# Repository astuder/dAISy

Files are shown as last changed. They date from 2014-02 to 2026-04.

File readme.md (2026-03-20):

dAISy - A simple DIY AIS Receiver
=================================

dAISy (do AIS yourself) is a simple AIS receiver based on Silicon Labs [Si4362 EZRadioPro](https://www.silabs.com/wireless/proprietary/ezradiopro-sub-ghz-ics/device.si4362) receiver, Texas Instruments [MSP430G2553](http://www.ti.com/product/msp430g2553) MCU and [MSP-EXP430G2](http://www.ti.com/tool/msp-exp430g2) v1.5 LaunchPad. The software was developed with Code Composer Studio 5.5.

AIS, short for "Automatic Identification System", is a tracking system for ships. More on [Wikipedia](http://en.wikipedia.org/wiki/Automatic_Identification_System). There are many websites dedicated to tracking ships based on this system, like for example [MarineTraffic](http://www.marinetraffic.com/).

dAISy features:
- integrated radio, no need for external radio with discriminator tap
- hopping between channel A (161.975 MHz) and B (162.025 MHz)
- receives, decodes and validates packets according to ITU-R M.1371-4 (NRZI decoding, bit-destuffing, CRC validation) 
- wraps valid packets into NMEA 0183 sentences (AIVDM)
- sends NMEA sentences to PC via serial (9600 8N1)

The output of dAISy can be processed and visualized by mapping and navigation programs like [OpenCPN](http://opencpn.org).

All content of this project is published under CC BY-SA - [Creative Commons Attribution-ShareAlike](http://creativecommons.org/licenses/by-sa/4.0/).  

A more detailed description of the project can be found in the [43oh.com forum](http://forum.43oh.com/topic/4833-potm-daisy-a-simple-ais-receiver/).

For those that just want the finished product: I sell the big sisters of dAISy in our [web store](https://shop.wegmatt.com).
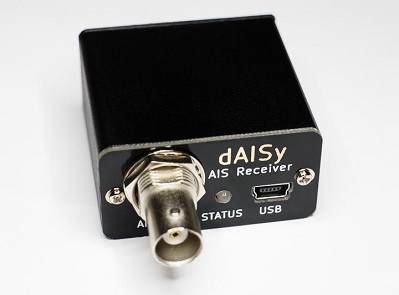
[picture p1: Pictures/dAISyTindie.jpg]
dAISy AIS Receiver


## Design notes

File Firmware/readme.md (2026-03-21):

# dAISy USB Firmware Updates

This folder contains firmware updates for the *single channel* dAISy receivers, also known as [dAISy USB](https://shop.wegmatt.com/products/daisy-ais-receiver).

DO NOT try to install this firmware on other dAISy devices. There are currently no updates for dAISy 2+ and dAISy HAT.

## Firmware History

* **4.16** June 26 2022
  - Added checks during boot to detect and gracefully handle fabrication errors.
  - Added information to debug menu if errors are detected during boot.
* **4.15** November 6 2021
  - Added support for Si4362-C2A radio IC.
  - Added support for MSP430F5502 MCU (HW version 4). Note separate firmware files!
  - Improved radio configuration for Si4467 and Si4362-C2A radios.
  - Fixed bug that discarded valid messages if CRC was followed by a stuff-bit.
  - Removed RSSI detect mode, it limited receiver sensitivity and range.
* **4.14** December 23 2017
  - Added smart channel hopping. This increases the number of received AIS messages by 40-60% compared to regular channel hopping.
  - Added support for NMEA loop-through of input from AUX serial. The enables forwarding of NMEA data, e.g. from a GPS receiver, to the connected PC.
  - Available only for [dAISy USB 3](https://shop.wegmatt.com/products/daisy-ais-receiver) (the ones sold in our store) and MSP430F5529 LaunchPad due to increased memory requirement.
* **4.12** July 1 2017
  - Minor optimization of radio configuration.
* **4.11** January 24 2017
  - Fixed bug to make dAISy work again with Android. This bug was introduced in version 4.10.
  - Slowed down channel hopping to twice per second. This improves the number of received messages by up to 25%.
  - Added command & to retrieve device serial number while in receive mode
  - Added support for input from AUX serial when enabled. However there still is no output of the debug menu on AUX serial.
* **4.08** May 30 2016
  - Added native support for Si4467 radio IC.
  - Added output of current configuration to debug menu.
  - Updated radio configuration for minor performance improvements.
* **4.07** March 13 2016
  - Fixed crash when receiving certain invalid AIS messages (endless loop spewing invalid AIS messages). 
  - Fixed crash when USB host goes into sleep (red LED blinking).
  - Added test mode that outputs a predefined AIS message every 5 second.
* **4.04** October 14 2015
  - Fixed reading channel configuration from FLASH memory.
  - Added debug option with TAB separated output for easier post processing of debug data.
* **4.03** September 6 2015
  - Finetuned crystal frequency to be closer to 30 MHz on average. Only minor improvement over 4.02, if any at all.
* **4.02** August 18 2015
  - Significantly improved reception of AIS messages over previous revisions. Greatly reduces number of errors, particularly for weak signals (below -80 dBm).

## Hardware Variants

There currently are 5 versions of the dAISy USB hardware. Make sure you download the right firmware for your version of dAISy!
Devices sold after August 2015 or running firmware 4.02 and newer will display their hardware and firmware version in the debug menu.

**hw4: dAISy USB 3 - square 2.1, MSP430F5502 MCU**

This is the hardware version introduced in November 2021 and [is currently sold in my store](https://shop.wegmatt.com/products/daisy-ais-receiver).
The first line of the debug menu says `dAISy USB 3 (5502)`
The MSP430 MCU is in a QFN package with the marking `M430 F5502`. Text on the back of the PCB says `dAISy USB 3`. 
Right-click *[here](https://github.com/astuder/dAISy/raw/master/Firmware/Daisy_hw4_fw4_15.txt)* and select *save link as* to download firmware version `4.15`.

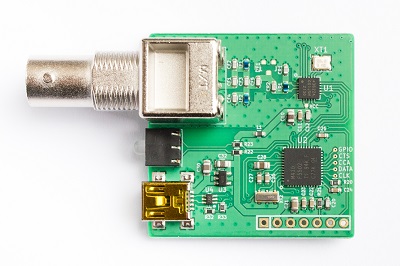
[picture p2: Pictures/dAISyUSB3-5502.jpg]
dAISy USB 3 MSP430F5502


**hw3: dAISy USB 3 - square 2, MSP430F5503 MCU**

This hardware version was sold up to early 2021.
The first line of the debug menu says `dAISy USB 3 (5503)`
The MSP430 MCU is in a QFN package with the marking `M430 F5503`. Text on the back of the PCB says `dAISy USB 3`. PCB color and component arrangement varies, some being identical to the F5502 variant shown above.
Right-click *[here](https://github.com/astuder/dAISy/raw/master/Firmware/Daisy_hw3_fw4_15.txt)* and select *save link as* to download firmware version `4.15`.

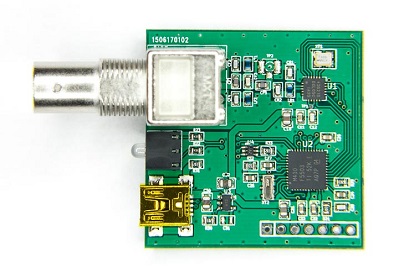
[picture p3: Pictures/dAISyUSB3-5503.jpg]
dAISy USB 3 MSP430F5503


**hw2: dAISy USB 2 - square 1, MSP430F5508 MCU**

This was the first version sold on Tindie (May, early June 2015). Note the MCU is in a QFP package (with leads). Text on the back says "dAISy USB 2".
PCB color can vary. Right-click *[here](https://github.com/astuder/dAISy/raw/master/Firmware/Daisy_hw2_fw4_11.txt)* and select *save link as* to download firmware version `4.11`.

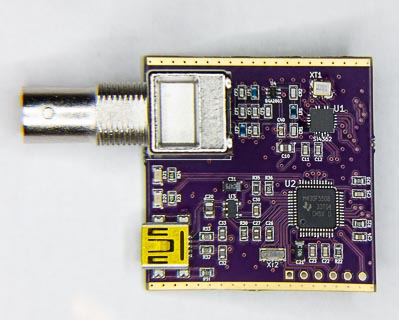
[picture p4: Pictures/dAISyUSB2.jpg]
dAISy USB 2


**hw1: dAISy USB - the stick, MSP430F5508 MCU**

The first version, mostly sold during 2014. Text on the back says "dAISy USB". Only a few brave souls have these :)
Right-click *[here](https://github.com/astuder/dAISy/raw/master/Firmware/Daisy_hw1_fw4_11.txt)* and select *save link as* to download firmware version `4.11`.

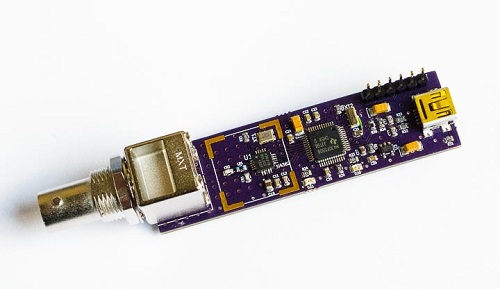
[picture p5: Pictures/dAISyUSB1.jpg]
dAISy USB 1


**hw0: dAISyPack - BoosterPack for the MSP430F5529 LaunchPad**

For the tinkerers among us. Text on the back says "dAISyPack". Hardware design file can be found *[here](../KiCad/dAISy%20BoosterPack)*.
Right-click *[here](https://github.com/astuder/dAISy/raw/master/Firmware/Daisy_hw0_fw4_14.txt)* and select *save link as* to download firmware.

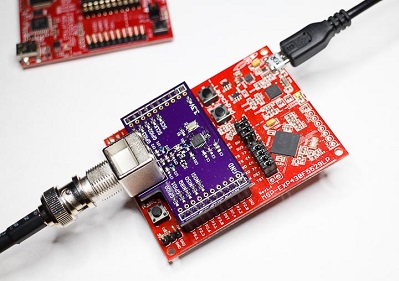
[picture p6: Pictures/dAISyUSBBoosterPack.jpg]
dAISyPack


## Updating the Firmware

To update the firmware, you need the programming software from TI. It's part of a bigger package, but for your convenience I made the relevant executable available [here](http://www.adrianstuder.com/daisy/BSL_USB_GUI.zip) (sorry, Windows only)

If you are currently running a firmware version older than 4.0, you will also need to update dAISy's USB driver. Use [this driver](http://www.adrianstuder.com/daisy/daisyUSB%20inf%20v2.zip), when Windows prompts you for a new driver after the upgrade.

**Upgrade procedure**

1.	Download the correct firmware file for your version of dAISy (see above). Save it in a folder path without Unicode characters, for example c:\dAISy\

2.	Verify that the firmware file is a plain text file. The filename must end with .txt and the content of the file should start with text similar to this:
	~~~~
	@8000
    5F 14 21 83 82 93 86 27 09 24 92 83 86 27 82 93 
    84 27 0A 20 F2 F0 7F 00 23 02 0B 3C B2 40 80 BB 
	~~~~
	If the file is not plain text (e.g. has HTML formatting), download it again. Make sure to download the RAW file, not the Github web page.

3.	Connect to dAISy with a serial terminal program, like for example Putty.
	- The serial connection parameters are: baud rate 38400, data bits 8, parity none, stop bits 1 (8n1), flow control none
	- Select or enter serial port. The serial port of dAISy can be found in the Windows Device Manger under Ports.
	- If you are not familiar with terminal programs, see [this document](http://www.microsemi.com/document-portal/doc_view/130815-configuring-serial-terminal-emulation-programs) for detailed configuration steps.

4.	Put dAISy into boot loader mode by sending the follwing commands through the serial terminal:
	- Press *ESC* to enter the debug menu.
	- The menu will display the current firmware version on the first line. You can stop here if your dAISy already runs the latest firmware.
	- Press *B* to start the boot loader.
	
	dAISy will now disable the serial port and is ready for the firmware update.

5.	Close the terminal program.

6.	Start *BSL_USB_GUI.exe*.

7.	Press *Next*, accept agreement, press *Next*.

8.	Choose option *Select Firmware* and browse to the firmware file provided.
	
	**IMPORTANT**: *DO NOT* program dAISy with the LED and Echo examples, it will brick the device!

9.	The *Upgrade Firmware* button should be active and “Found 1 device” is displayed below the button.
	- If not, make sure dAISy is connected and you entered bootloader mode as described above.
	- If that does not work, connect dAISy directly to your computer without a USB hub and try again.
	
10.	Press Upgrade Firmware.
	
	The upgrade should only take a few seconds.
	If the firmware upgrade fails with an error, make sure you use the correct firmware file.
	After a failed firmware update, dAISy will usually start in bootloader mode after a power-cycle. Retry this procedure starting
	at step 6.

11.	After successful upgrade, dAISy should be available again.

	In some cases you might need to disconnect and reconnect dAISy.

12.	The version information in the debug menu should now read:

	*dAISy USB v4.xx* followed by hardware information, e.g. *dAISy USB 3 (5503)*

If you bricked dAISy in the process of upgrading it, you can try to revive it following the instructions on [this page](./unbrick-daisy.md).
	
Please let me know if you run into any problems. Also don't hesitate to contact me if this all sounds too complicated, you don't have a Windows machine,
and/or don't have a resident geek to ask for help.

I also offer to perform free firmware upgrades if you cover the shipping cost.

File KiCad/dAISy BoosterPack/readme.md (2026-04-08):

Breakout board for the Si446x as MSP430 BoosterPack. 

dAISyPack

Paired with a [TI MSP430F5529 LaunchPad](https://www.ti.com/tool/MSP-EXP430F5529LP), this board can also be used with the (closed source) [dAISy USB firmware](https://github.com/astuder/dAISy/tree/master/Firmware).

This breakout board is also the basis of [this project](https://github.com/NSwiz1/msp430-si4467-ais-audio-receiver), which uses the Raw or Sync data from the Si446x for audio input into ShipPlotter software.

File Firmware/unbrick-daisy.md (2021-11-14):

# Un-bricking dAISy

When the firmware update is interrupted, or the wrong firmware file was uploaded, dAISy me be unresponsive. This page describes the procedure to revive dAISy. 

## Is it truly bricked?

Before doing it the hard way, verify the following steps:

1. Unplug dAISy from your computer, wait a few seconds, and plug it in again. Does Windows make a sound and detect a USB device?

2. Start *BSL_USB_GUI.exe* and click Next and accept the agreement. Does it say "Found 1 device" under the Upgrade Firmware button?

If the above is true, you are lucky and dAISy is still alive. It recovered from a failed firmware update and entered the bootloader. 
You can try again to upgrade the firmware by starting at step 6 of the [update instructions](./readme.md#updating-the-firmware). Make sure you select the correct version, contact me if in doubt.
If upgrade fails repeatedly, try without USB hub or from a different PC.

If dAISy is not detected by the BSL USB GUI tool, then it is truly bricked.

## Un-bricking procedure

Follow the steps below to manually force dAISy into boot loader mode.

1. Unplug dAISy's USB cable from your computer.

2. Remove the two screws on the front and slide the circuit board out of the enclosure.

3. Use a piece of jumper wire and stick one end into the pad marked with 3V3.

5. Board Rev G and newer: With one hand, hold the other end of the wire to the right end of resistor R32 as shown below.
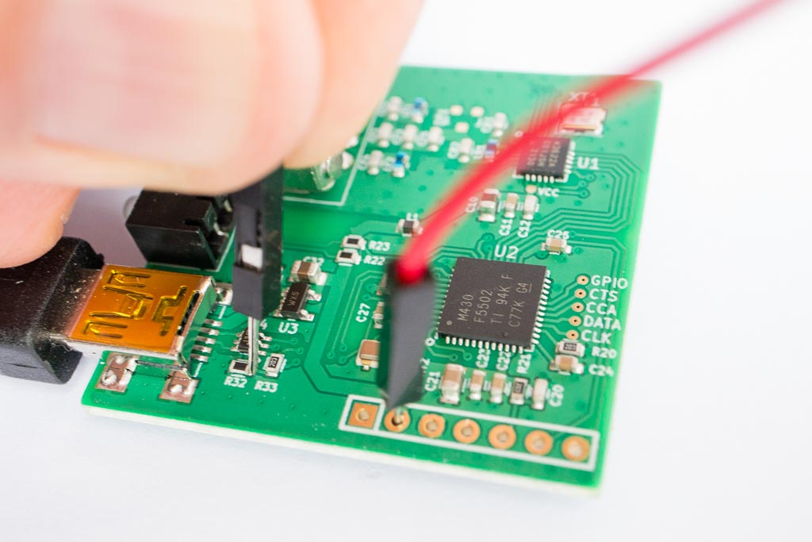
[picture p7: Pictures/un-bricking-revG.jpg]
unbricking dAISy 3 Rev G and newer

Older board revisions: With one hand, hold the other end of the wire to the left end of resistor R32 as shown below.
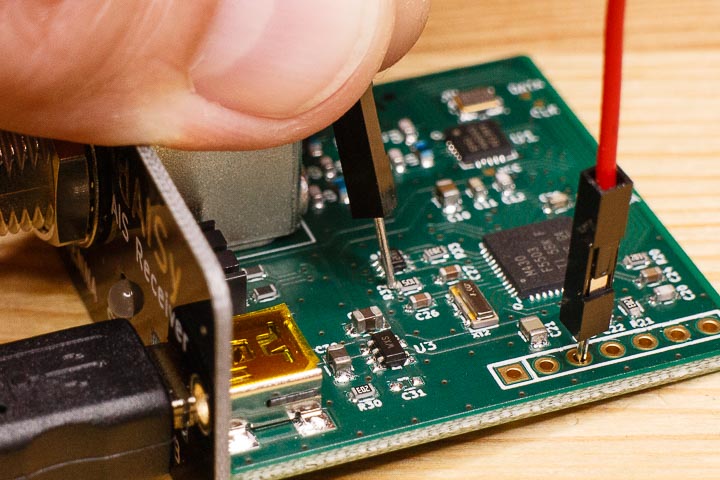
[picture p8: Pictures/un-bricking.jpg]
unbricking dAISy 3 for older board revisions
 

6. With the other hand, plug the USB cable back into the computer - you should hear the USB detect sound of Windows.

7. Remove the wire.

8. dAISy should now be in boot loader mode and you can retry the firmware upgrade starting at step 5 of the [upgrade instructions](./readme.md#updating-the-firmware).

If all this fails, or simply sounds too complicated, please contact me and I will exchange your bricked dAISy for a working one.

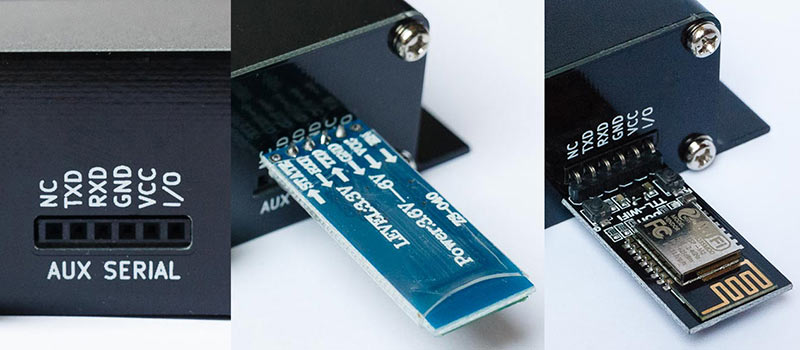
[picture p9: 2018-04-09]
Pictures/dAISy2PlusSerial.jpg

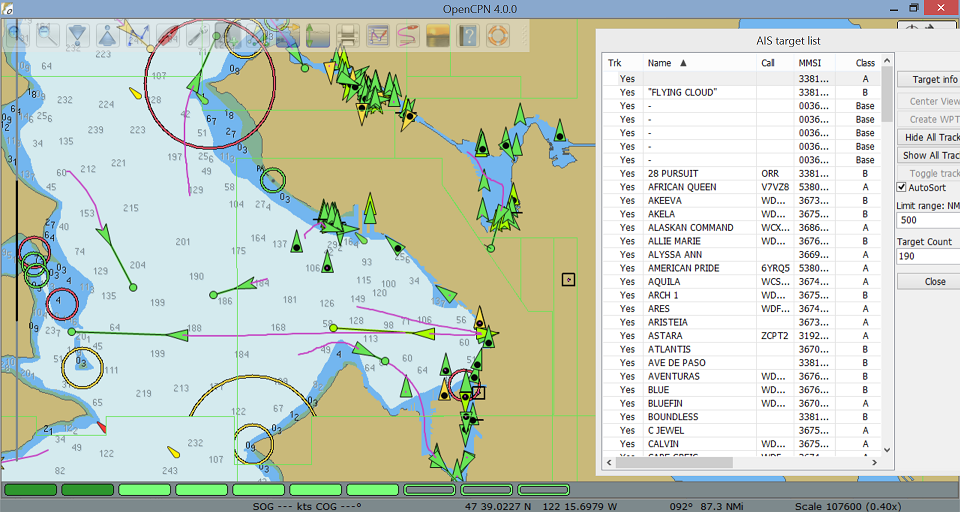
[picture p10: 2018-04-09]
Pictures/opencpn screen small.png

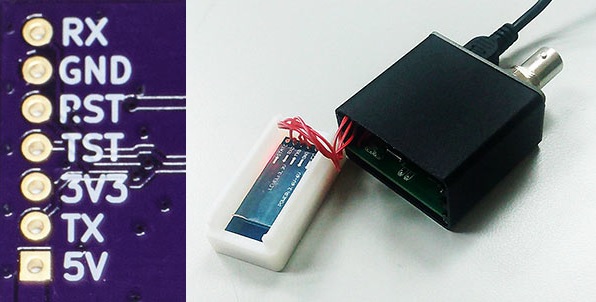
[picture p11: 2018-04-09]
Pictures/dAISy AUX serial.jpg

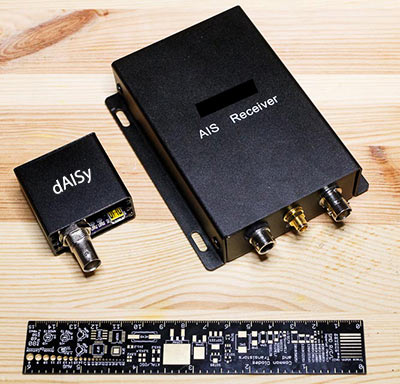
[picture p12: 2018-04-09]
Pictures/daisy size comparison.jpg

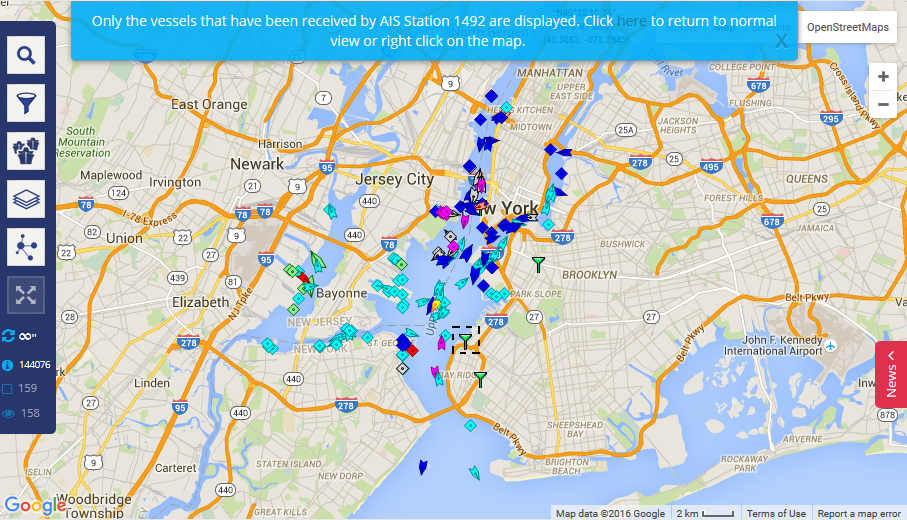
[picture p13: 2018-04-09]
Pictures/MarineTraffic 1492-2.png

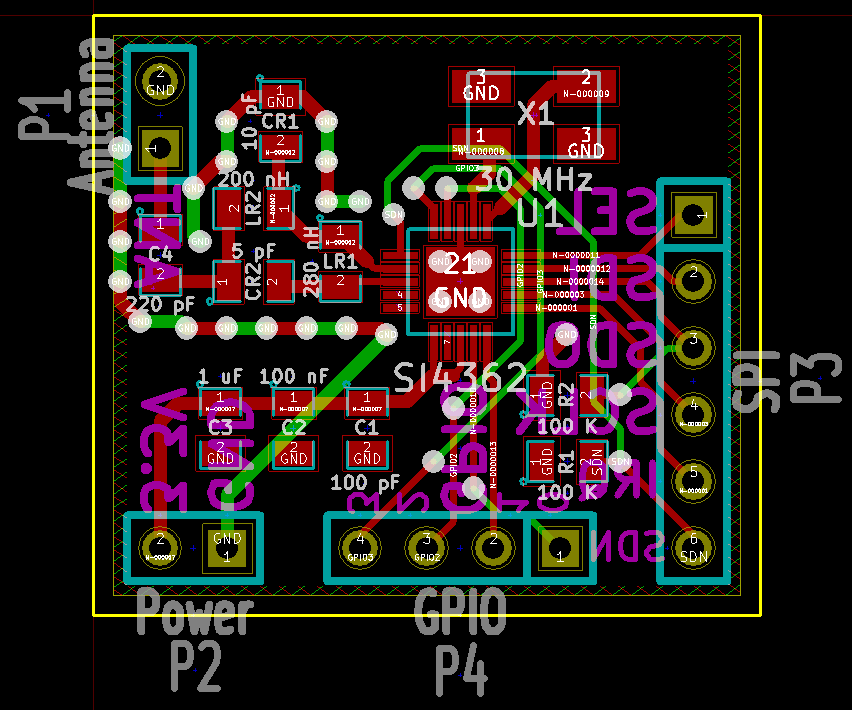
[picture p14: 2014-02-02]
KiCad/Si446x Breakout/layout.png

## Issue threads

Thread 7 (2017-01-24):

uart_send_string() problem

nazmibojan, 2017-01-24:
Hello Astuder!
I have one question about send string over uart. In main.c we can see:

uart_send_string("dAISy 0.2 started\r\n");

after radio_get_chip_status().
If I unplugged the dAISy receiver, I could see blinking led that indicate the error of radio_get_chip_status().
But if I plugged the dAISy I couldn't find 'dAISy 0.2 started' printed in my serial terminal.
How could it happen?
Sorry for the noobs question.

Regards,
Rian

astuder, 2017-01-24:
Hi Rian,

Unless you reset/restart dAISy with a serial terminal open, the startup message will be lost. If you are using a LaunchPad, you may be able to see the message when you press the reset button.

Regards,
Adrian

nazmibojan, 2017-01-24:
It works!
Thanks Astuder.
Sorry for the noobs question :D

Regards,
Rian

astuder, 2017-01-24:
no problem

Closed 2017-01-24.

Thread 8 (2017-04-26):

Error when Importing dAISy AIS Project in CCS v6

nazmibojan, 2017-04-26:
Hello Astuder,
Thanks for sharing the codes. When I imported the codes in CCS v6 I got this error:

  _Error: Import failed for project 'dAISy' because its meta-data cannot be interpreted. Please contact support._

Any solution?
Thanks.

Salam,
Nazmi

astuder, 2017-04-27:
Downloading the project as ZIP from Github and importing works for me with CSS 6.1.

PS: Please only use Github issues for actual bugs. Questions like these, any questions actually, are better handled in the dAISy thread on the 43oh forum.
http://forum.43oh.com/topic/4833-potm-daisy-a-simple-ais-receiver/

Closed 2017-04-27.

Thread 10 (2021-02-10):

raspberry CM4 IO board design idea

mgrouch, 2021-02-10:
raspberry CM4 and IO boards look very promising. I thought since you made dAISy you might be able to design a more complete board.

https://www.raspberrypi.org/products/compute-module-4-io-board/

There is a company which offers free design of the board on their web site
if you use their web site to spec it out.

Here is the link

https://www.gumstix.com/community/special-offer/

Their design studio

https://geppetto.gumstix.com/#!/dashboard/

Add number of NMEA interfaces, GPS, IMU, few 1-wire, One N2K
Safe Shutdown, 12v power in (+ AIS Chip possiblly)

to original CM4 IO Board and it could make a nice marine board
replacing MCS and Moitessier Hat combo

using raspberry CM4.

Just an idea

Thanks,
--MG

mgrouch, 2021-12-20:
There is more progress with CM4 boards.

There are few from Waveshare and MCUZone which can be very close to what boat users would like.

Enclosure might need just few improvements.

Coupled with  Bareboat Necessities OS (which is mature) as firmware
it could be an interesting product.

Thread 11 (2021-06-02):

NavTex USB idea

mgrouch, 2021-06-02:
Based on success of dAISy AIS might be you could make
a small NavTex receiver connectable
via USB. And outside antenna. There is one NASA Marine PC NavTex USB
which is way too expensive.
There is software too to display messages https://github.com/juerec/pc-navtex

thanks,
—MG

astuder, 2021-06-03:
I thought about it before, but never found a suitable IC that covers the required frequencies (490 and 518 kHz) and is still in production. So the radio portion may have to be built from discrete transistors etc. I'm not much of a radio buff, but if someone has a working design that they want to get turned into a dAISy-equivalent I'd be happy to collaborate.

PS: I don't think that the NASA NavTex receivers are overpriced, at least not compared to what other marine electronics vendors charge. :)

astuder, 2021-06-03:
Here's my link collection of various (old-school) designs:
http://www.michaelhompus.nl/Navtex.htm
http://www.harpoon.si/uploads/Razvoj%20podpora/Navtex.pdf
https://www.qsl.net/pa2ohh/07fer.htm

mgrouch, 2021-06-04:
Found these products:

Seems even more interesting than just NASA NavTex. More weather features

http://www.wetterinfobox.com/english/WIBE.htm

Sent from my iPhone

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

astuder, 2021-06-04:
And you thought NASA was expensive :)
https://moerer.de/seewetterberichte/wetterinfoboxen/
Doesn't look like they sell the USB version any longer.

mgrouch, 2021-06-05:
Now I think Nasa PC NavTex is not overpriced if I only get it to work.
So far 9 hours and not a single NavTex message received.

On Fri, Jun 4, 2021 at 5:53 PM Adrian Studer ***@***.***>
wrote:

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

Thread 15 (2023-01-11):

[ASK] Downloading firmware into new MCU

handiko, 2023-01-11:
Hi Adrian,
My name is Handiko. I want to make your dAISy hardware on my own. I have read in your https://github.com/astuder/dAISy/tree/master/Firmware that to download the firmware, as I understand, the MCU needs to be flashed with the bootloader first. Is that true? If I want to make my own PCB and solder my new MSP430F5502 MCU, can I just use the Daisy_hw4_fw4_15.txt file? Do I still need the bootloader? Any info will be very much appreciated. Thank you and great project!

astuder, 2023-01-11:
Hi Handiko,

The files and documentation in the Firmware folder are for the USB version of the dAISy, which is a device that I sell.

The basic AIS receiver documented in the root and KiCad folder of this repository is the foundation of that product, but doesn't support USB. Instead it uses UART to output AIS as a serial data stream. Implementing a USB device would require quite a bit of additional work.

For development purposes I program my MSP430s by using a LaunchPad dev board like [MSP-EXP430F5529LP](https://www.ti.com/tool/MSP-EXP430F5529LP), connecting power, ground, RST and TEST to my own board. TI's Code Composer Studio and UniFlash tool recognize LaunchPads as programmers.

I hope this answers your question. You're welcome to contact me through the email address on my profile page if you have more questions.

Best Regards,
Adrian

handiko, 2023-01-11:
Hi Adrian,
I have further questions but I'm sorry I can't find your email on your profile page. It doesn't show up on my end. Could you please kindle provide your email address? Thank you.

Regards,
Handiko

astuder, 2023-01-11:
Oh, for some unknown reason the email disappeared from my profile. It's now back, a few lines under the profile bio. You must be logged in to see it.

astuder, 2023-01-11:
Sorry, just noticed that I now can only use the email associated with my GitHub account instead of an arbitrary email address. 👎

I don't want to publish the former, so I had to remove it again. You can contact me at adrian at adrianstuder dot com.

Closed 2023-01-11.

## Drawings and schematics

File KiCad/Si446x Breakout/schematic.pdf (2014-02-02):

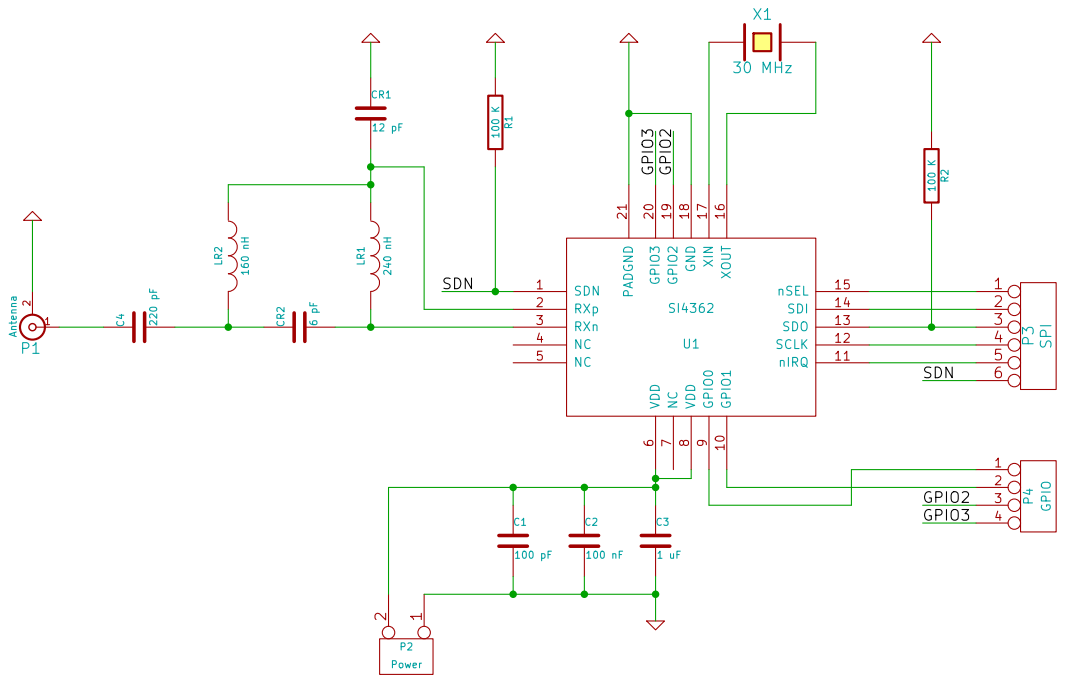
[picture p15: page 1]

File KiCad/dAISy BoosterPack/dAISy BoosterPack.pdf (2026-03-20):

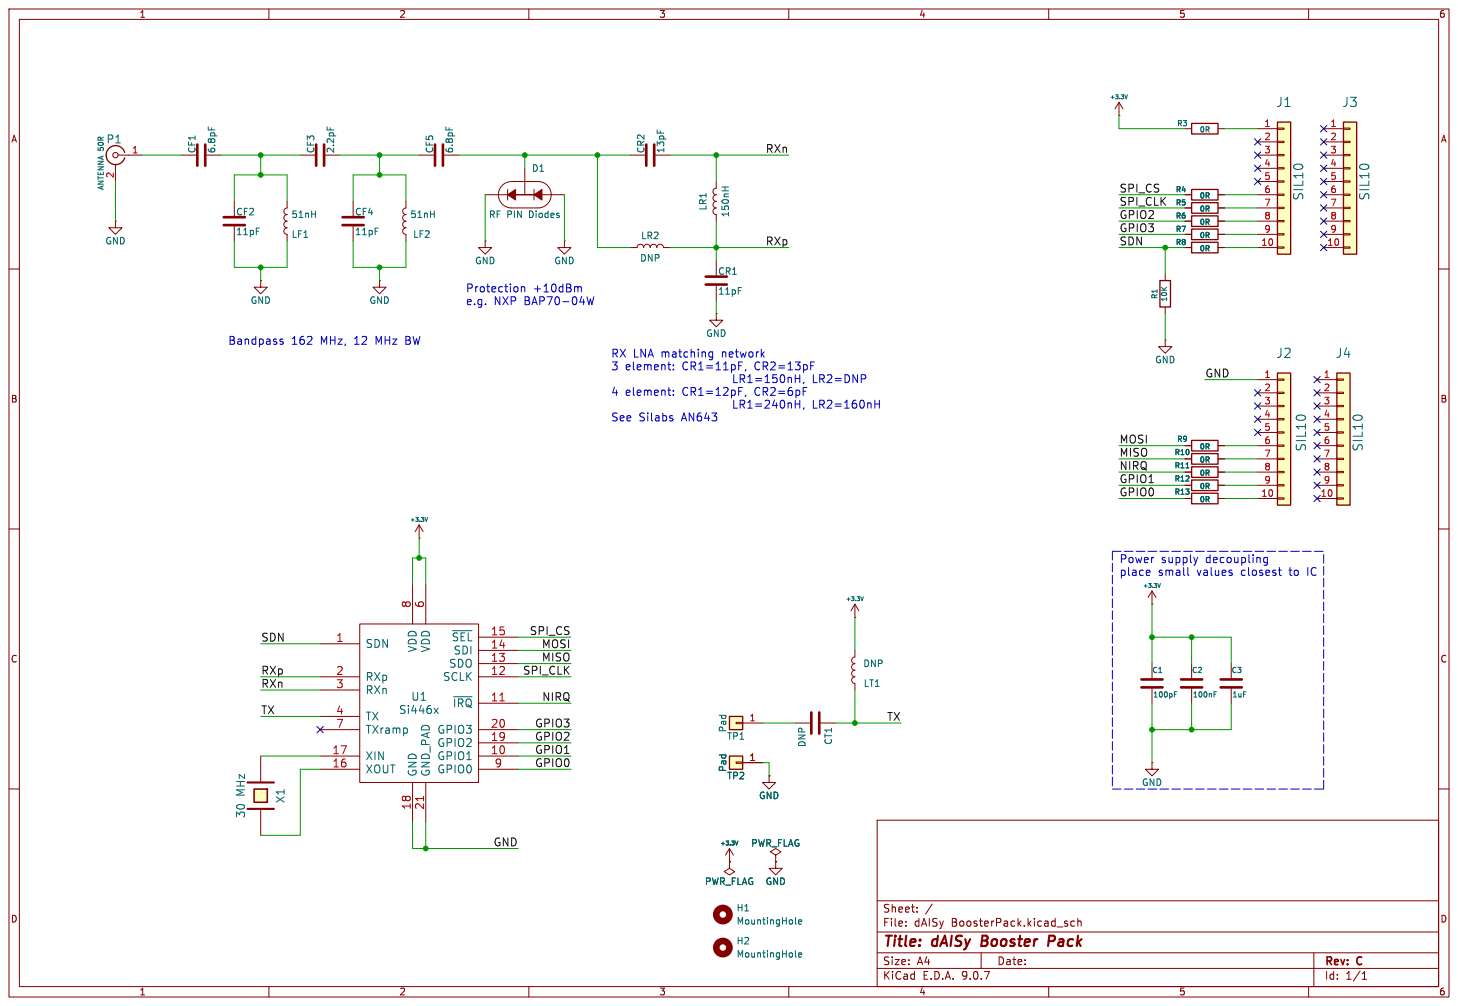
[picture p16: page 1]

Bandpass 162 MHz, 12 MHz BW

place small values closest to IC

Id: 1/1 Title: dAISy Booster Pack

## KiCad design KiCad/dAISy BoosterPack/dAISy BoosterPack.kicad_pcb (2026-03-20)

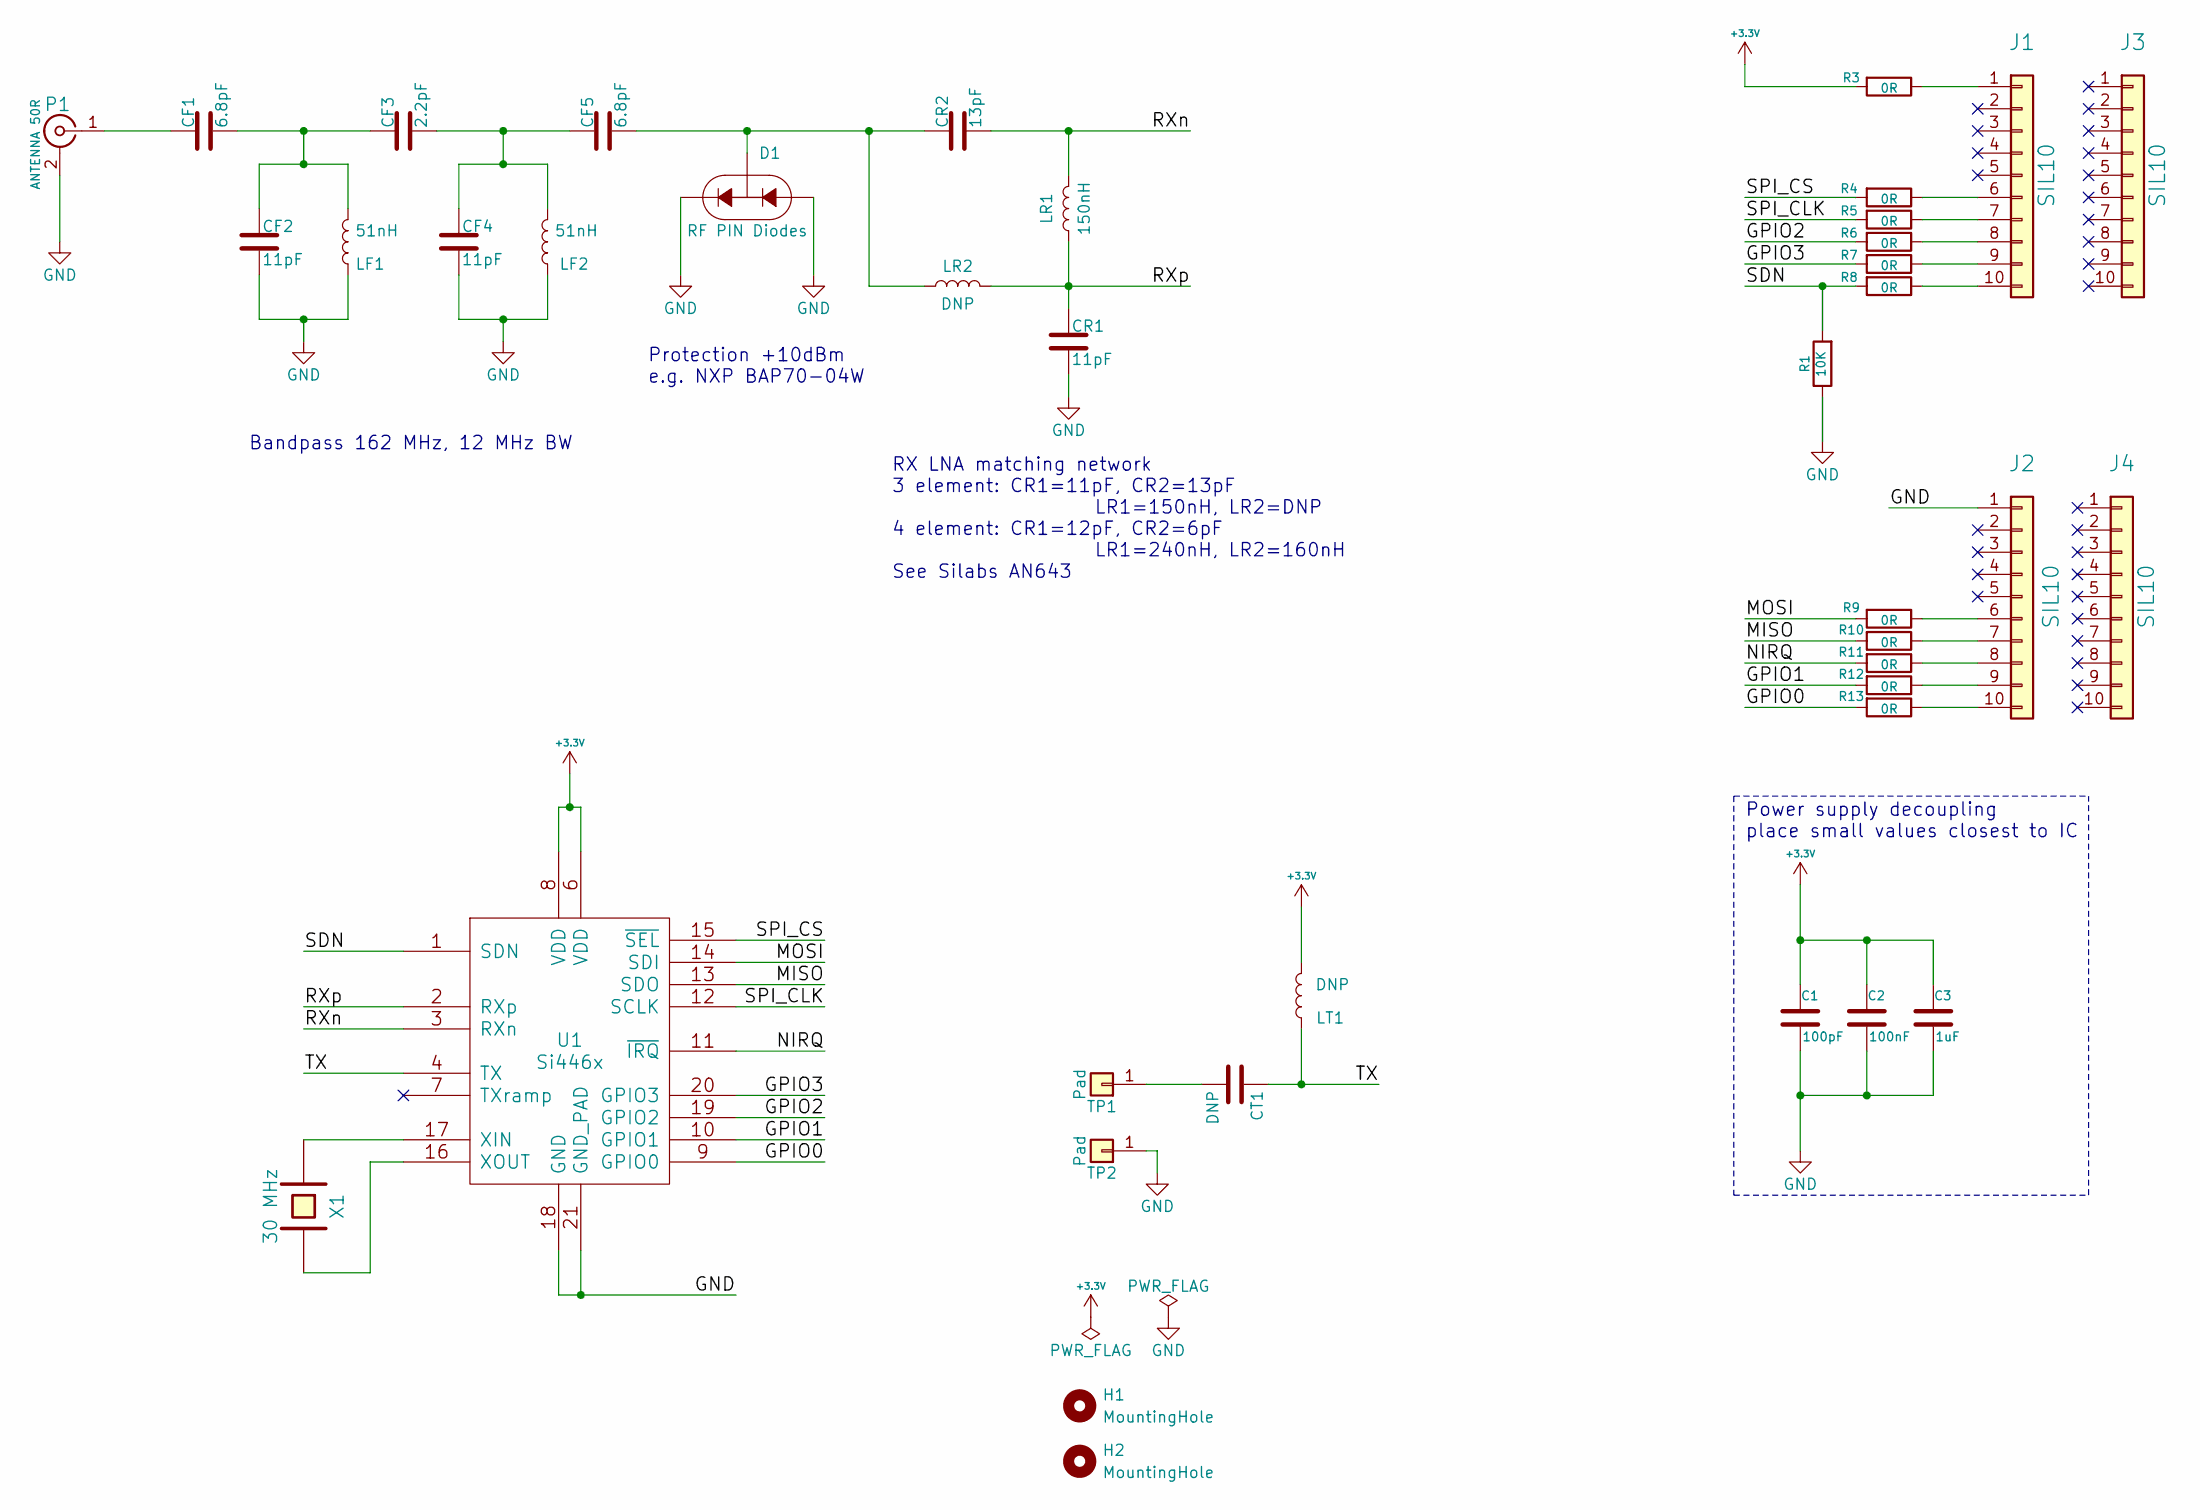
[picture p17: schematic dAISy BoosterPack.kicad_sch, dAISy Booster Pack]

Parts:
C1: 100pF; C_0603_1608Metric_Pad1.08x0.95mm_HandSolder
C2: 100nF; C_0603_1608Metric_Pad1.08x0.95mm_HandSolder
C3: 1uF; C_0603_1608Metric_Pad1.08x0.95mm_HandSolder
CF1, CF5: 6.8pF; C_0603_1608Metric_Pad1.08x0.95mm_HandSolder
CF2, CF4: 11pF; C_0603_1608Metric_Pad1.08x0.95mm_HandSolder
CF3: 2.2pF; C_0603_1608Metric_Pad1.08x0.95mm_HandSolder
CR1: 11pF; C_0603_1608Metric_Pad1.08x0.95mm_HandSolder
CR2: 13pF; C_0603_1608Metric_Pad1.08x0.95mm_HandSolder
CT1: DNP; C_0603_1608Metric_Pad1.08x0.95mm_HandSolder
D1: RF PIN Diodes; SOT-323_SC-70_Handsoldering
H1, H2: MountingHole; MountingHole_2.5mm
J1, J2: SIL10; SIL-10-W
J3, J4: SIL10; SIL-10-W-no-silk
LF1, LF2: 51nH; C_0603_1608Metric_Pad1.08x0.95mm_HandSolder
LR1: 150nH; C_0603_1608Metric_Pad1.08x0.95mm_HandSolder
LR2: DNP; C_0603_1608Metric_Pad1.08x0.95mm_HandSolder
LT1: DNP; C_0603_1608Metric_Pad1.08x0.95mm_HandSolder
P1: ANTENNA 50R; BNC_Molex_73138-5033
R1: 10K; R_0603_1608Metric_Pad0.98x0.95mm_HandSolder
R3, R4, R5, R6, R7, R8, R9, R10, R11, R12, R13: 0R; R_0603_1608Metric_Pad0.98x0.95mm_HandSolder
TP1, TP2: Pad; TestPoint_THTPad_D1.5mm_Drill0.7mm
U1: Si446x; QFN-20_long_pads
X1: 30 MHz; Crystal-32x25

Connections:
+3.3V: C1.1, C2.1, C3.1, LT1.2, R3.2, U1.6 (VDD), U1.8 (VDD)
/GPIO0: R13.2, U1.9 (GPIO0)
/GPIO1: R12.2, U1.10 (GPIO1)
/GPIO2: R6.2, U1.19 (GPIO2)
/GPIO3: R7.2, U1.20 (GPIO3)
/MISO: R10.2, U1.13 (SDO)
/MOSI: R9.2, U1.14 (SDI)
/NIRQ: R11.2, U1.11 (~IRQ)
/RXn: CR2.2, LR1.2, U1.3 (RXn)
/RXp: CR1.1, LR1.1, LR2.2, U1.2 (RXp)
/SDN: R1.2, R8.2, U1.1 (SDN)
/SPI_CLK: R5.2, U1.12 (SCLK)
/SPI_CS: R4.2, U1.15 (~SEL)
/TX: CT1.1, LT1.1, U1.4 (TX)
GND: C1.2, C2.2, C3.2, CF2.2, CF4.2, CR1.2, D1.1, D1.2, J2.1, LF1.1, LF2.1, P1.2 (Ext), R1.1, TP2.1, U1.18 (GND), U1.21 (GND_PAD), X1.2 (GND)
unnamed: CF1.2, CF2.1, CF3.1, LF1.2
unnamed: CF3.2, CF4.1, CF5.1, LF2.2
unnamed: CF5.2, CR2.1, D1.3, LR2.1
unnamed: J1.1, R3.1
unnamed: J1.6, R4.1
unnamed: J1.7, R5.1
unnamed: J1.8, R6.1
unnamed: J1.9, R7.1
unnamed: J1.10, R8.1
unnamed: J2.6, R9.1
unnamed: J2.7, R10.1
unnamed: J2.8, R11.1
unnamed: J2.9, R12.1
unnamed: J2.10, R13.1
unnamed: CF1.1, P1.1 (In)
unnamed: CT1.2, TP1.1
unnamed: U1.17 (XIN), X1.1
unnamed: U1.16 (XOUT), X1.3

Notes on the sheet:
Bandpass 162 MHz, 12 MHz BW
RX LNA matching network 3 element: CR1=11pF, CR2=13pF LR1=150nH, LR2=DNP 4 element: CR1=12pF, CR2=6pF LR1=240nH, LR2=160nH See Silabs AN643
Power supply decoupling place small values closest to IC
Protection +10dBm e.g. NXP BAP70-04W

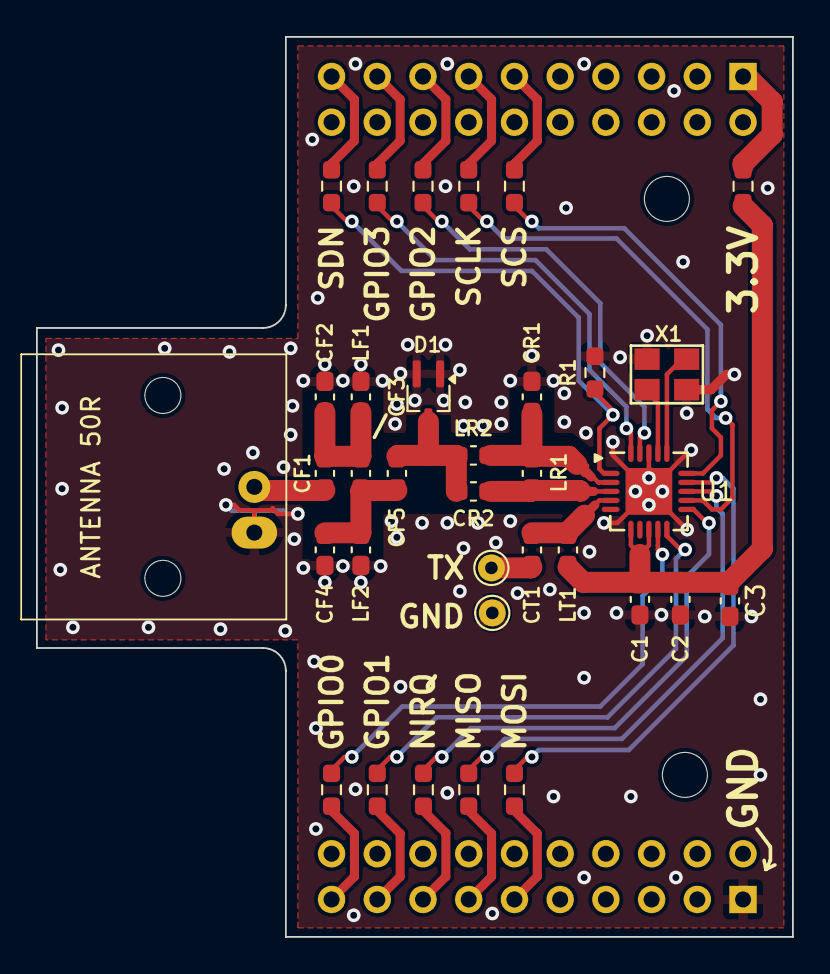
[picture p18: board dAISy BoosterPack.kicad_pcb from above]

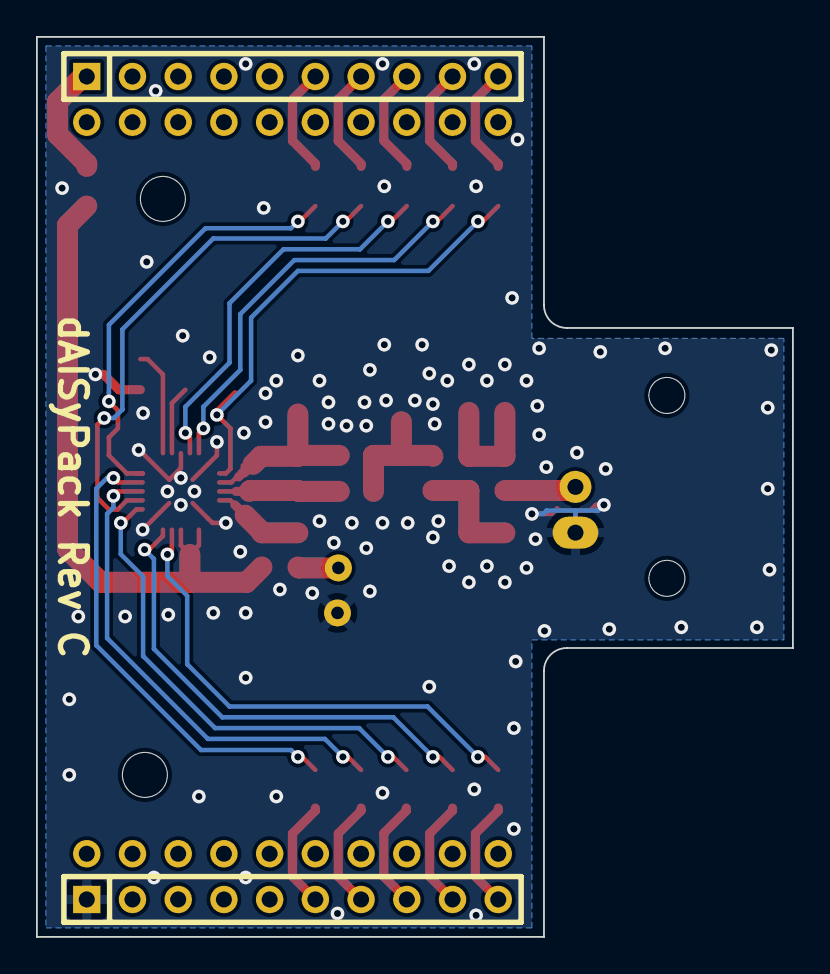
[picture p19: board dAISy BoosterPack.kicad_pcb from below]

Board: 2 copper layers, 42.0 x 50.0 mm, 40 parts (4 on the bottom side), 33 nets.

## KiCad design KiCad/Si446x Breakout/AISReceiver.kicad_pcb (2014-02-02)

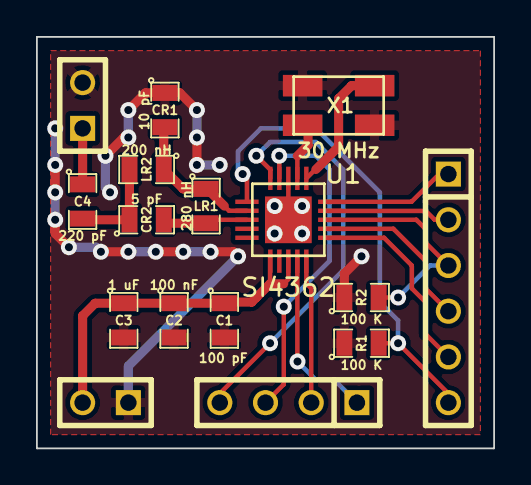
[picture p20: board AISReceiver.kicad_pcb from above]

Board: 2 copper layers, 25.4 x 22.9 mm, 16 parts (0 on the bottom side), 18 nets.

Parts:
C1: 100 pF; SM0805
C2: 100 nF; SM0805
C3: 1 uF; SM0805
C4: 220 pF; SM0805
CR1: 10 pF; SM0805
CR2: 5 pF; SM0805
LR1: 280 nH; SM0805
LR2: 200 nH; SM0805
P1: Antenna; SIL-2
P2: Power; SIL-2
P3: SPI; SIL-6
P4: GPIO; SIL-4
R1, R2: 100 K; SM0805
U1: SI4362; QFN20+1
X1: 30 MHz; Crystal-50x32

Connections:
/GPIO2: P4.3, U1.19
/GPIO3: P4.4, U1.20
/SDN: P3.6, R1.2, U1.1
GND: C1.2, C2.2, C3.2, CR1.1, P1.2, P2.1, R1.1, R2.1, U1.18, U1.21, X1.3
unnamed: P3.5, U1.11
unnamed: CR1.2, LR1.1, LR2.1, U1.2
unnamed: P3.4, U1.12
unnamed: C1.1, C2.1, C3.1, P2.2, U1.6, U1.8
unnamed: U1.17, X1.1
unnamed: U1.16, X1.2
unnamed: P4.1, U1.9
unnamed: P3.1, U1.15
unnamed: P3.2, U1.14
unnamed: P4.2, U1.10
unnamed: P3.3, R2.2, U1.13
unnamed: C4.1, P1.1
unnamed: CR2.2, LR1.2, U1.3
unnamed: C4.2, CR2.1, LR2.2

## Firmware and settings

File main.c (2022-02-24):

/*
 * dAISy 0.2 - A simple AIS receiver
 * Author: Adrian Studer
 * License: CC BY-SA Creative Commons Attribution-ShareAlike
 * 			https://creativecommons.org/licenses/by-sa/4.0/
 * 			Please contact the author if you want to use this work in a closed-source project
 */

#include <msp430.h> 
#include <inttypes.h>

#include "fifo.h"
#include "uart.h"
#include "dec_to_str.h"

#include "radio.h"
#include "packet_handler.h"
#include "nmea.h"

#define DEBUG_MESSAGES			// un-comment to send error messages over UART

// LED helpers for debugging
#define LED1	BIT0
#define LED1_ON		P1OUT |= LED1
#define LED1_OFF 	P1OUT &= ~LED1
#define LED1_TOGGLE	P1OUT ^= LED1

#ifdef TEST
void test_main(void);
void test_packet_handler(const char* message);
void test_error(void);
#endif

#ifdef DEBUG_MESSAGES
char str_output_buffer[5];	// output buffer for numbers in some debug messages
#endif

int main(void)
{
	// configure WDT
	WDTCTL = WDTPW | WDTHOLD;				// stop watch dog timer

	// set clock to 16MHz
	BCSCTL1 = CALBC1_16MHZ;
	DCOCTL = CALDCO_16MHZ;
	BCSCTL2 = 0;							// MCLK and SMCLK = DCO = 16MHz

#ifdef TEST
	// when compiled in test mode, use different main
	// disconnect radio when testing to avoid damage!
	test_main();
#endif

	// configure LED1 and turn it off, we'll use that for error and other stuff
	P1DIR |= LED1;
	LED1_OFF;

	// setup uart
	uart_init();

	// setup packet handler
	ph_setup();

	// setup an configure radio
	radio_setup();
	radio_configure();

	// verify that radio configuration was successful
	radio_get_chip_status(0);
	if (radio_buffer.chip_status.chip_status & RADIO_CMD_ERROR) {	// check for command error
		while (1) {
			LED1_TOGGLE;
			_delay_cycles(8000000);			// blink LED if there was an error
		}
	}

	// start packet receiving
	ph_start();

#ifdef DEBUG_MESSAGES
	uart_send_string("dAISy 0.2 started\r\n");
#endif

	while (1) {

		__low_power_mode_4();	// deep sleep until something worthwhile happens

#ifdef DEBUG_MESSAGES
		uint8_t channel;
		int16_t rssi;
		// debug code to monitor signal strength (RSSI)
		if (ph_get_state() == PH_STATE_PREFETCH) {											// found preamble and start flag
			// record current channel and signal strength
			channel = ph_get_radio_channel();												// read current channel
			rssi = ph_get_radio_rssi();														// read current RSSI
		}
#endif

		// retrieve last packet handler error
		uint8_t error = ph_get_last_error();
#ifdef DEBUG_MESSAGES
		// report error if packet handler failed
		if (error != PH_ERROR_NONE)	{
			dec_to_str(str_output_buffer, 3, rssi);											// convert to decimal string (reuse radio buffer)
			str_output_buffer[4] = 0;														// terminate string
			uart_send_string("sync ");														// send debug message to UART
			uart_send_byte(channel + 'A');
			uart_send_string(" RSSI=");
			uart_send_string(str_output_buffer);
			uart_send_string("dBm\r\n");
			uart_send_string("error: ");
			switch (error) {
			case PH_ERROR_NOEND:
				uart_send_string("no end flag");
				break;
			case PH_ERROR_STUFFBIT:
				uart_send_string("invalid stuff bit");
				break;
			case PH_ERROR_CRC:
				uart_send_string("CRC error");
				break;
			case PH_ERROR_RSSI_DROP:
				uart_send_string("RSSI drop");
				break;
			}
			uart_send_string("\r\n");
		}
#else
		// toggle LED if packet handler failed after finding preamble and start flag
		if (error == PH_ERROR_NOEND || error == PH_ERROR_STUFFBIT || error == PH_ERROR_CRC)
			LED1_TOGGLE;
#endif

		// check if a new valid packet arrived
		uint16_t size = fifo_get_packet();
		if (size > 0) {								// if so, process packet

#ifdef DEBUG_MESSAGES
			dec_to_str(str_output_buffer, 3, rssi);											// convert to decimal string (reuse radio buffer)
			str_output_buffer[4] = 0;														// terminate string
			uart_send_string("sync ");														// send debug message to UART
			uart_send_byte(channel + 'A');
			uart_send_string(" RSSI=");
			uart_send_string(str_output_buffer);
			uart_send_string("dBm\r\n");
#endif

			nmea_process_packet();					// process packet (NMEA message will be sent over UART)
			fifo_remove_packet();					// remove processed packet from FIFO
		}

		// enter low power mode LPM0 (everything off)
		// TODO: wait for UART to complete transmission

		// TODO: suspend UART
	}
}

#ifdef TEST
// AIS test messages, more samples see http://www.aishub.net/nmea-sample.html
const char test_message_0[] = "133sVfPP00PD>hRMDH@jNOvN20S8";
const char test_message_1[] = "13u?etPv2;0n:dDPwUM1U1Cb069D";
const char test_message_2[] = "100h00PP0@PHFV`Mg5gTH?vNPUIp";


void test_main(void)
{
	radio_shutdown();	// put radio into shutdown to avoid damage when writing to radio output pins

	// testing dec_to_str
	char test_buf[10];
	const uint32_t a = 1023;
	udec_to_str(test_buf, 9, a);
	const int32_t b = -1023;
	dec_to_str(test_buf, 9, b);

	// setup uart
	uart_init();

	// setup packet handler
	ph_setup();
	test_ph_setup();

	// start packet receiving
	ph_start();

	while (1) {
		// testing packet handler
		_delay_cycles(10000000);
		test_packet_handler(test_message_0);
		_delay_cycles(10000000);
		test_packet_handler(test_message_1);
		_delay_cycles(10000000);
		test_packet_handler(test_message_2);
	}
}

void test_packet_handler(const char* message)
{
	// send/receive fake AIS message
	test_ph_send_packet(message);

	// verify packet handler operation
	if (ph_get_last_error() != PH_ERROR_NONE)
		test_error();

	// verify if a new packet showed up in FIFO
	uint16_t packet_size = fifo_get_packet();
	if (packet_size == 0)
		test_error();

	// verify if new packet is identical with sent message
	if (!test_nmea_verify_packet(message))
		test_error();

	nmea_process_packet();

	// remove packet from FIFO
	fifo_remove_packet();
}

void test_error(void)
{
	while (1) {
		LED1_TOGGLE;
		_delay_cycles(8000000);			// blink LED if there was an error
	}
}

#endif

// handler for unexpected interrupts
#pragma vector=ADC10_VECTOR,COMPARATORA_VECTOR,NMI_VECTOR,PORT1_VECTOR,	\
			   TIMER0_A0_VECTOR,TIMER0_A1_VECTOR,TIMER1_A0_VECTOR,TIMER1_A1_VECTOR,		\
			   USCIAB0RX_VECTOR,USCIAB0TX_VECTOR,WDT_VECTOR
__interrupt void ISR_trap(void)
{
	// trap CPU & code execution here with an infinite loop
	while (1);
}

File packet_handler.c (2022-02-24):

/*
 * AIS packet handler for MSP430 + Si4362
 * Author: Adrian Studer
 * License: CC BY-SA Creative Commons Attribution-ShareAlike
 *          https://creativecommons.org/licenses/by-sa/4.0/
 *          Please contact the author if you want to use this work in a closed-source project
 */

#include <msp430.h>
#include <inttypes.h>

#include "radio.h"
#include "fifo.h"
#include "packet_handler.h"

// LED helpers for debugging
#define LED1	BIT0
#define LED1_ON		P1OUT |= LED1
#define LED1_OFF 	P1OUT &= ~LED1
#define LED1_TOGGLE	P1OUT ^= LED1

// sync word for AIS - only used for test
#define AIS_SYNC_WORD		0x7e

// paramters for package detection
#define PH_PREAMBLE_LENGTH	8		// minimum number of alternating bits we need for a valid preamble
#define PH_SYNC_TIMEOUT	16			// number of bits we wait for a preamble to start before changing channel
//#define PH_RSSI_THRESHOLD -95		// threshold in dBm for valid signal, comment out to ignore signal strength

// pins that packet handler uses to receive data
#define	PH_DATA_CLK_PIN		RADIO_GPIO_2	// RX data clock
#define PH_DATA_PIN			RADIO_GPIO_3	// RX data
#define PH_DATA_PORT		RADIO_PORT	  	// data pins are on port 2 (only ports 1 and 2 supported)

// data port dependent defines
#if (PH_DATA_PORT == 1)
#define PH_DATA_IN P1IN
#define PH_DATA_OUT P1OUT
#define PH_DATA_SEL P1SEL
#define PH_DATA_DIR P1DIR
#define PH_DATA_IFG P1IFG
#define PH_DATA_IE P1IE
#define PH_DATA_IES P1IES
#define PH_DATA_PORT_VECTOR PORT1_VECTOR
#elif (PH_DATA_PORT == 2)
#define PH_DATA_IN P2IN
#define PH_DATA_OUT P2OUT
#define PH_DATA_SEL P2SEL
#define PH_DATA_DIR P2DIR
#define PH_DATA_IFG P2IFG
#define PH_DATA_IE P2IE
#define PH_DATA_IES P2IES
#define PH_DATA_PORT_VECTOR PORT2_VECTOR
#else
#error "Packet handler only supports port 1 and 2."
#endif

// preamble and start flag detection states
enum PH_SYNC_STATE {
	PH_SYNC_RESET = 0,			// reset/restart sync detection
	PH_SYNC_0,					// last bit was a 0
	PH_SYNC_1,					// last bit was a 1
	PH_SYNC_FLAG				// detecting start flag
};

volatile uint8_t ph_state = PH_STATE_OFF;
volatile uint8_t ph_last_error = PH_ERROR_NONE;
volatile uint8_t ph_radio_channel = 0;
volatile uint8_t ph_message_type = 0;
volatile int16_t ph_rssi = 0;

// setup packet handler
void ph_setup(void)
{
	// configure data pins as inputs
	PH_DATA_SEL &= ~(PH_DATA_CLK_PIN | PH_DATA_PIN);
	PH_DATA_DIR &= ~(PH_DATA_CLK_PIN | PH_DATA_PIN);
	fifo_reset();
}

// start packet handler operation, including ISR
void ph_start(void)
{

#ifndef TEST
	#ifdef PH_RSSI_THRESHOLD
	// set radio RSSI threshold
	radio_set_property(0x20, 0x4a, RADIO_DBM_TO_RSSI(PH_RSSI_THRESHOLD));
	#endif

	// start radio, wait until it's spun up
	radio_start_rx(ph_radio_channel, 0, 0, RADIO_STATE_NO_CHANGE, RADIO_STATE_NO_CHANGE, RADIO_STATE_NO_CHANGE);
	radio_wait_for_CTS();
#endif

	// reset packet handler state machine
	ph_last_error = PH_ERROR_NONE;
	ph_radio_channel = 0;
	ph_state = PH_STATE_RESET;

	// enable interrupt on positive edge of pin wired to DATA_CLK (GPIO2 as configured in radio_config.h)
	PH_DATA_IES &= ~PH_DATA_CLK_PIN;
	PH_DATA_IE |= PH_DATA_CLK_PIN;
	_BIS_SR(GIE);      			// enable interrupts

	// ISR is now running and will operate radio, don't call radio library until ph ISR is stopped.
}

// interrupt handler for receiving raw modem data via DATA/DATA_CLK pins
#pragma vector=PH_DATA_PORT_VECTOR
__interrupt void ph_irq_handler(void)
{
	static uint16_t rx_bitstream;				// shift register with incoming data
	static uint16_t rx_bit_count;				// bit counter for various purposes
	static uint16_t rx_crc;						// word for AIS payload CRC calculation
	static uint8_t rx_one_count;				// counter of 1's to identify stuff bits
	static uint8_t rx_data_byte;				// byte to receive actual package data
	uint8_t rx_this_bit_NRZI;					// current bit for NRZI decoding
	static uint8_t rx_prev_bit_NRZI;			// previous bit for NRZI decoding
	uint8_t rx_bit;								// current decoded bit
	static uint8_t rx_sync_state;				// state of preamble and start flag detection
	static uint8_t rx_sync_count;				// length of valid bits in current sync sequence

	uint8_t wake_up = 0;						// if set, LPM bits will be cleared

	LED1_ON;

	if ((PH_DATA_IFG & PH_DATA_CLK_PIN)			// verify this interrupt is from DATA_CLK/GPIO_2 pin
			&& RADIO_READY) {					// and only process data received while radio ready

		// read data bit and decode NRZI
		if (PH_DATA_IN & PH_DATA_PIN)						// read encoded data bit from line
			rx_this_bit_NRZI = 1;
		else
			rx_this_bit_NRZI = 0;

		rx_bit = !(rx_prev_bit_NRZI ^ rx_this_bit_NRZI); 	// NRZI decoding: change = 0-bit, no change = 1-bit, i.e. 00,11=>1, 01,10=>0, i.e. NOT(A XOR B)
		rx_prev_bit_NRZI = rx_this_bit_NRZI;				// store encoded bit for next round of decoding

		// add decoded bit to bit-stream (receiving LSB first)
		rx_bitstream >>= 1;
		if (rx_bit)
			rx_bitstream |= 0x8000;

		// packet handler state machine
		switch (ph_state) {

	// STATE: OFF
		case PH_STATE_OFF:									// state: off, do nothing
			break;

	// STATE: RESET
		case PH_STATE_RESET:								// state: reset, prepare state machine for next packet
			rx_bitstream &= 8000;							// reset bit-stream (but don't throw away incoming bit)
			rx_bit_count = 0;								// reset bit counter
			fifo_new_packet();								// reset fifo packet
			fifo_write_byte(ph_radio_channel);				// indicate channel for this packet
			ph_state = PH_STATE_WAIT_FOR_SYNC;				// next state: wait for training sequence
			rx_sync_state = PH_SYNC_RESET;
			break;

	// STATE: WAIT FOR PREAMBLE AND START FLAG
		case PH_STATE_WAIT_FOR_SYNC:						// state: waiting for preamble and start flag
			rx_bit_count++;									// count processed bits since reset

	  // START OF SYNC STATE MACHINE
			switch (rx_sync_state) {

		// SYNC STATE: RESET
			case PH_SYNC_RESET:								// sub-state: (re)start sync process
				if (rx_bit_count > PH_SYNC_TIMEOUT)			// if we exceeded sync time out
					ph_state = PH_STATE_RESET;				// reset state machine, will trigger channel hop
				else {										// else
					rx_sync_count = 0;						// start new preamble
					if (rx_bit)
						rx_sync_state = PH_SYNC_1;			// we started with a 1
					else
						rx_sync_state = PH_SYNC_0;			// we started with a 0
				}
				break;

		  // SYNC STATE: 0-BIT
			case PH_SYNC_0:									// sub-state: last bit was a 0
				if (rx_bit) {								// if we get a 1
					rx_sync_count++;							// valid preamble bit
					rx_sync_state = PH_SYNC_1;					// next state
				} else {									// if we get another 0
					if (rx_sync_count > PH_PREAMBLE_LENGTH)	{	// if we have a sufficient preamble length
						rx_sync_count = 7;							// treat this as part of start flag, we already have 1 out of 8 bits (0.......)
						rx_sync_state = PH_SYNC_FLAG;				// next state flag detection
					}
					else										// if not
						rx_sync_state = PH_SYNC_RESET;				// invalid preamble bit, restart preamble detection
				}
				break;
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

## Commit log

2013-12-18 AIS-6: Calculate and verify CRC
    incl. extended test routine
    incl. fixing code to match conventions
    [main.c, packet_handler.c]
2013-12-23 AIS-13 implemented basic serial out
    plus some cleanup in SPI lib
2013-12-24 AIS-25 AIS-26 NMEA processing
    send received packets as NMEA sentences over UART
2013-12-24 fixed missing UART init
    added more debug code
    [main.c]
2013-12-24 clear last error when read
    [packet_handler.c]
2013-12-25 bugfix: increase NMEA fragment count
    [nmea.c]
2013-12-25 add reference to thread on 43oh.com
2013-12-28 hardware schematic (KiCad)
    [AISReceiver-B_Cu.gbl, AISReceiver-B_Mask.gbs, AISReceiver-B_SilkS.gbo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]
2014-01-06 Channel Hopping
    implemented channel hopping, added IR calibration, plus some refactoring
2014-01-06 fix for radio hanging
    using radio in Direct RX, i.e. disabled hardware packet handler as it
    might interfere with software implementation. added some debug LED code
    to packet handler
    [radio.c, radio.h]
2014-01-13 bug fixes and LPM
    tested and fixed AIS, shortened preamble to 12 bits, rolled back radio
    configuration to known-good state, put MCU into LPM4
    [main.c, nmea.c, packet_handler.c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]
2014-01-15 inlined SPI transfer
2014-02-02 Rev B schematic and layout
    [AISReceiver-B_Cu.gbl, AISReceiver-B_Mask.gbs, AISReceiver-B_SilkS.gbo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]
2014-07-13 added Kicad library cache
2014-11-09 IR calibration according to AN790
2015-02-23 fixed preamble to start flag transition
    [packet_handler.c]
2015-02-23 updated CCS configuration to ignore Kicad folder
2016-03-13 add error check for too empty message
    [nmea.c]
2018-01-02 Clarified devices to which this firmware applies
2022-04-18 fixed link to Silabs website
    https://www.silabs.com/wireless/proprietary/ezradiopro-sub-ghz-ics/device.si4362
2026-03-20 add dAISy BoosterPack KiCad project
    [AISReceiver-B_Cu.gbl, AISReceiver-B_Mask.gbs, AISReceiver-B_SilkS.gbo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]
